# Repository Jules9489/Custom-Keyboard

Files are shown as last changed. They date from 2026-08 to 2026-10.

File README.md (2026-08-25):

# Custom-Keyboard

Plan:

65% Keyboard

Rotary Encoder for Media Controls 

Foam Padding in the Case 

Result:

A nice-looking 65% keyboard that has a rotary encoder for media controls.

It took me a while to make because I ran into different problems along the way, but I managed to fix them eventually. I learned a bit of RMK and a bit more about PCB design, as I had previously made a MacroPad using QMK but had a few flaws, and so I was able to learn from my previous mistakes to make this project better. I built this because I was going to buy a keyboard for my laptop, but then I saw this competition and decided to do it myself.

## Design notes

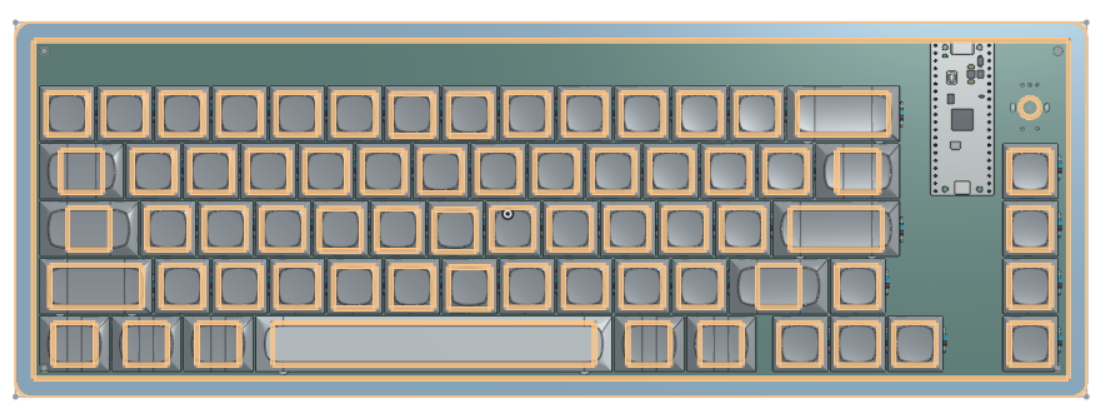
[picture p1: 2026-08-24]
Images/Finished Keyboard plate design.png

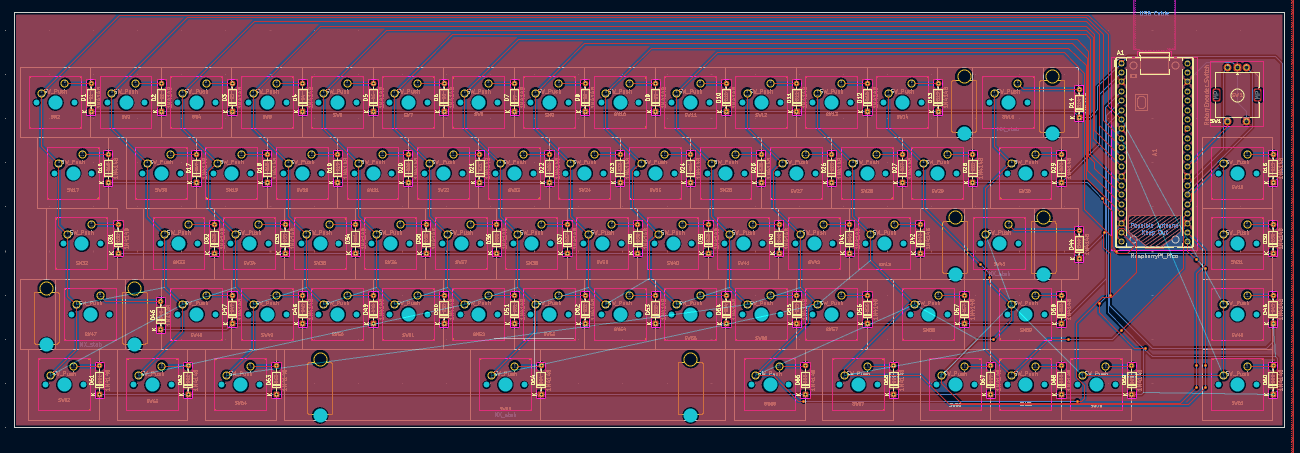
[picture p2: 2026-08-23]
Images/NotCompletedPCB.png

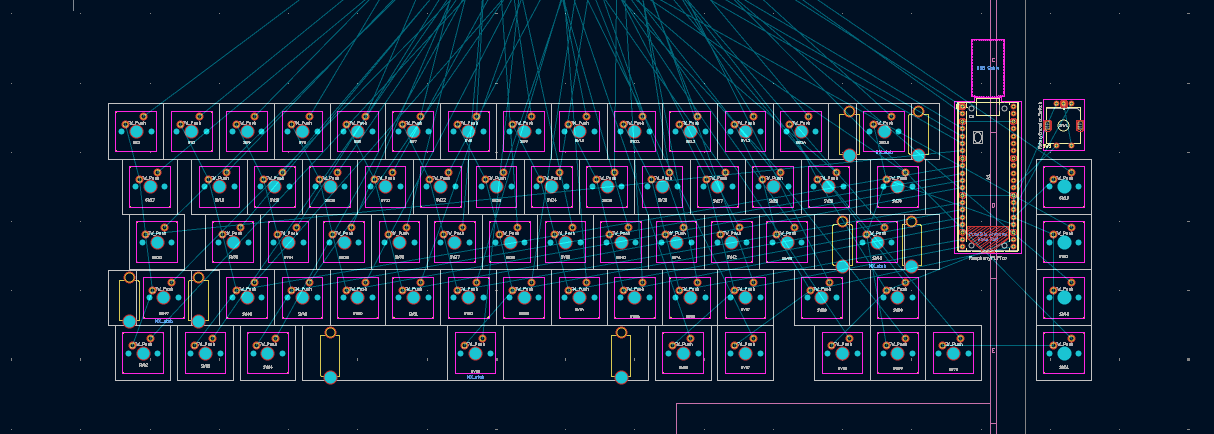
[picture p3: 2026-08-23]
Images/Keyboardlayout.png

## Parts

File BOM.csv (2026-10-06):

Id | Designator | Footprint | Quantity | Designation | Supplier and ref
1 | D39,D10,D55,D16,D58,D1,D57,D61,D18,D30,D64,D28,D23,D45,D41,D66,D2,D62,D56,D4,D29,D38,D24,D22,D43,D17,D21,D12,D52,D53,D25,D9,D5,D31,D42,D11,D37,D6,D60,D49,D36,D63,D51,D67,D20,D8,D32,D65,D15,D19,D48,D47,D7,D3,D54,D14,D46,D26,D13,D44,D33,D40,D59,D35,D27,D50,D34 | D_DO-35_SOD27_P7.62mm_Horizontal | 67 | 1N4148 | https://www.aliexpress.com/item/1005009379098965.html?mp=1 | $3.91
2 | SW52,SW11,SW24,SW63,SW28,SW12,SW38,SW57,SW55,SW8,SW16,SW17,SW26,SW61,SW58,SW40,SW51,SW50,SW4,SW15,SW56,SW2,SW47,SW41,SW44,SW39,SW67,SW10,SW21,SW9,SW45,SW59,SW49,SW19,SW43,SW14,SW3,SW53,SW20,SW13,SW54,SW30,SW36,SW27,SW34,SW48,SW31,SW33,SW65,SW7,SW66,SW64,SW46,SW42,SW5,SW32,SW25,SW23,SW18,SW22,SW68,SW62,SW6,SW35,SW60,SW37,SW29 | SW_MX_1u | 67 | SW_Push | https://www.aliexpress.com/item/1005010169995953.html?mp=1 | $19.03
3 | S1,S2,S3,S4 | STAB_MX_P_2u | 2 | MX_stab | https://www.aliexpress.com/item/1005004286282216.html?mp=1 | $23.75
4 | SW1 | ROT_Alps_EC11E-Switch | 1 | RotaryEncoder_Switch |  | free
5 | A1 | RaspberryPi_Pico_Common_THT | 1 | RaspberryPi_Pico | https://www.aliexpress.com/item/1005008948799927.html?curPageLogUid=gA2XHZhrixAo | $3.59
6 |  | Eva Foam |  | 1 | https://www.aliexpress.com/item/1005002856054113.html?mp=1
7 |  | Flux |  | 1 | https://www.aliexpress.com/item/1005010513692131.html?mp=1 | $1.35
8 |  | Desoldering wick |  | 1 | https://www.aliexpress.com/item/1005008563077640.html?mp=1 | $1.35
9 |  | O rings |  | 1 | https://www.aliexpress.com/item/1005008292633323.html?mp=1 | $1.35
10 |  | Keycap set |  | 1 | https://www.aliexpress.com/item/1005009502593166.html?mp=1 | $31.68
11 |  | PCB |  | 1 |  | $24.40

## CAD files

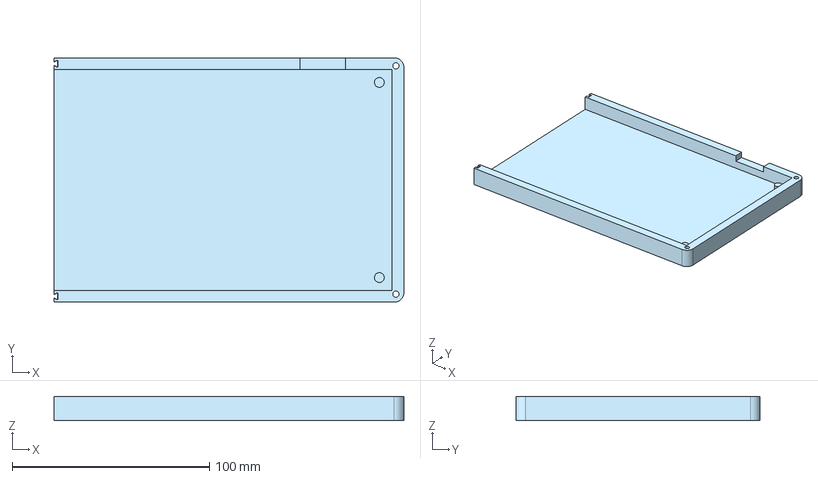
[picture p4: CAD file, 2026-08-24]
CAD/Part Studio 4 - Part 2.step
177.4 x 123.9 x 12.3 mm

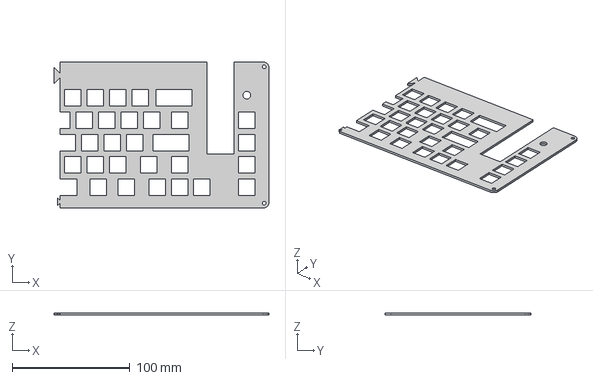
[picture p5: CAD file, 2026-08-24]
CAD/Part Studio 4 - Part 4.step
182.4 x 123.9 x 2.00 mm

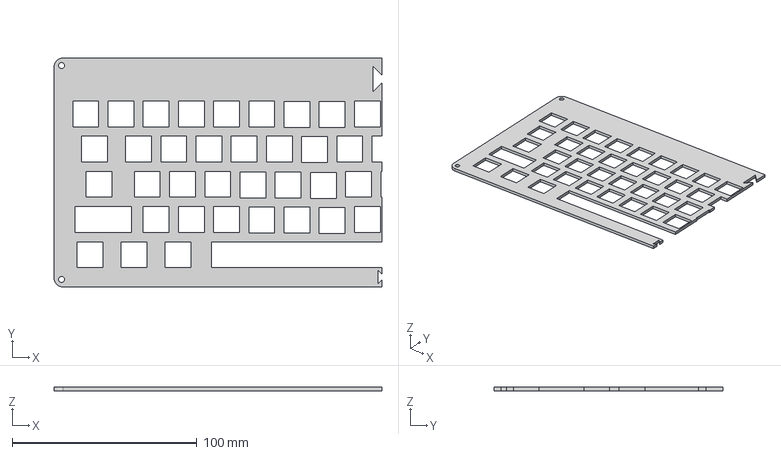
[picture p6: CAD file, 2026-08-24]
CAD/Part Studio 4 - Part 3.step
177.5 x 123.9 x 2.00 mm

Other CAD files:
CAD/Part Studio 4 - Part 1.step
CAD/Part Studio 4 - Part 1.3mf
CAD/Part Studio 4 - Part 2.3mf
CAD/Part Studio 4 - Part 3.3mf
CAD/Part Studio 4 - Part 4.3mf

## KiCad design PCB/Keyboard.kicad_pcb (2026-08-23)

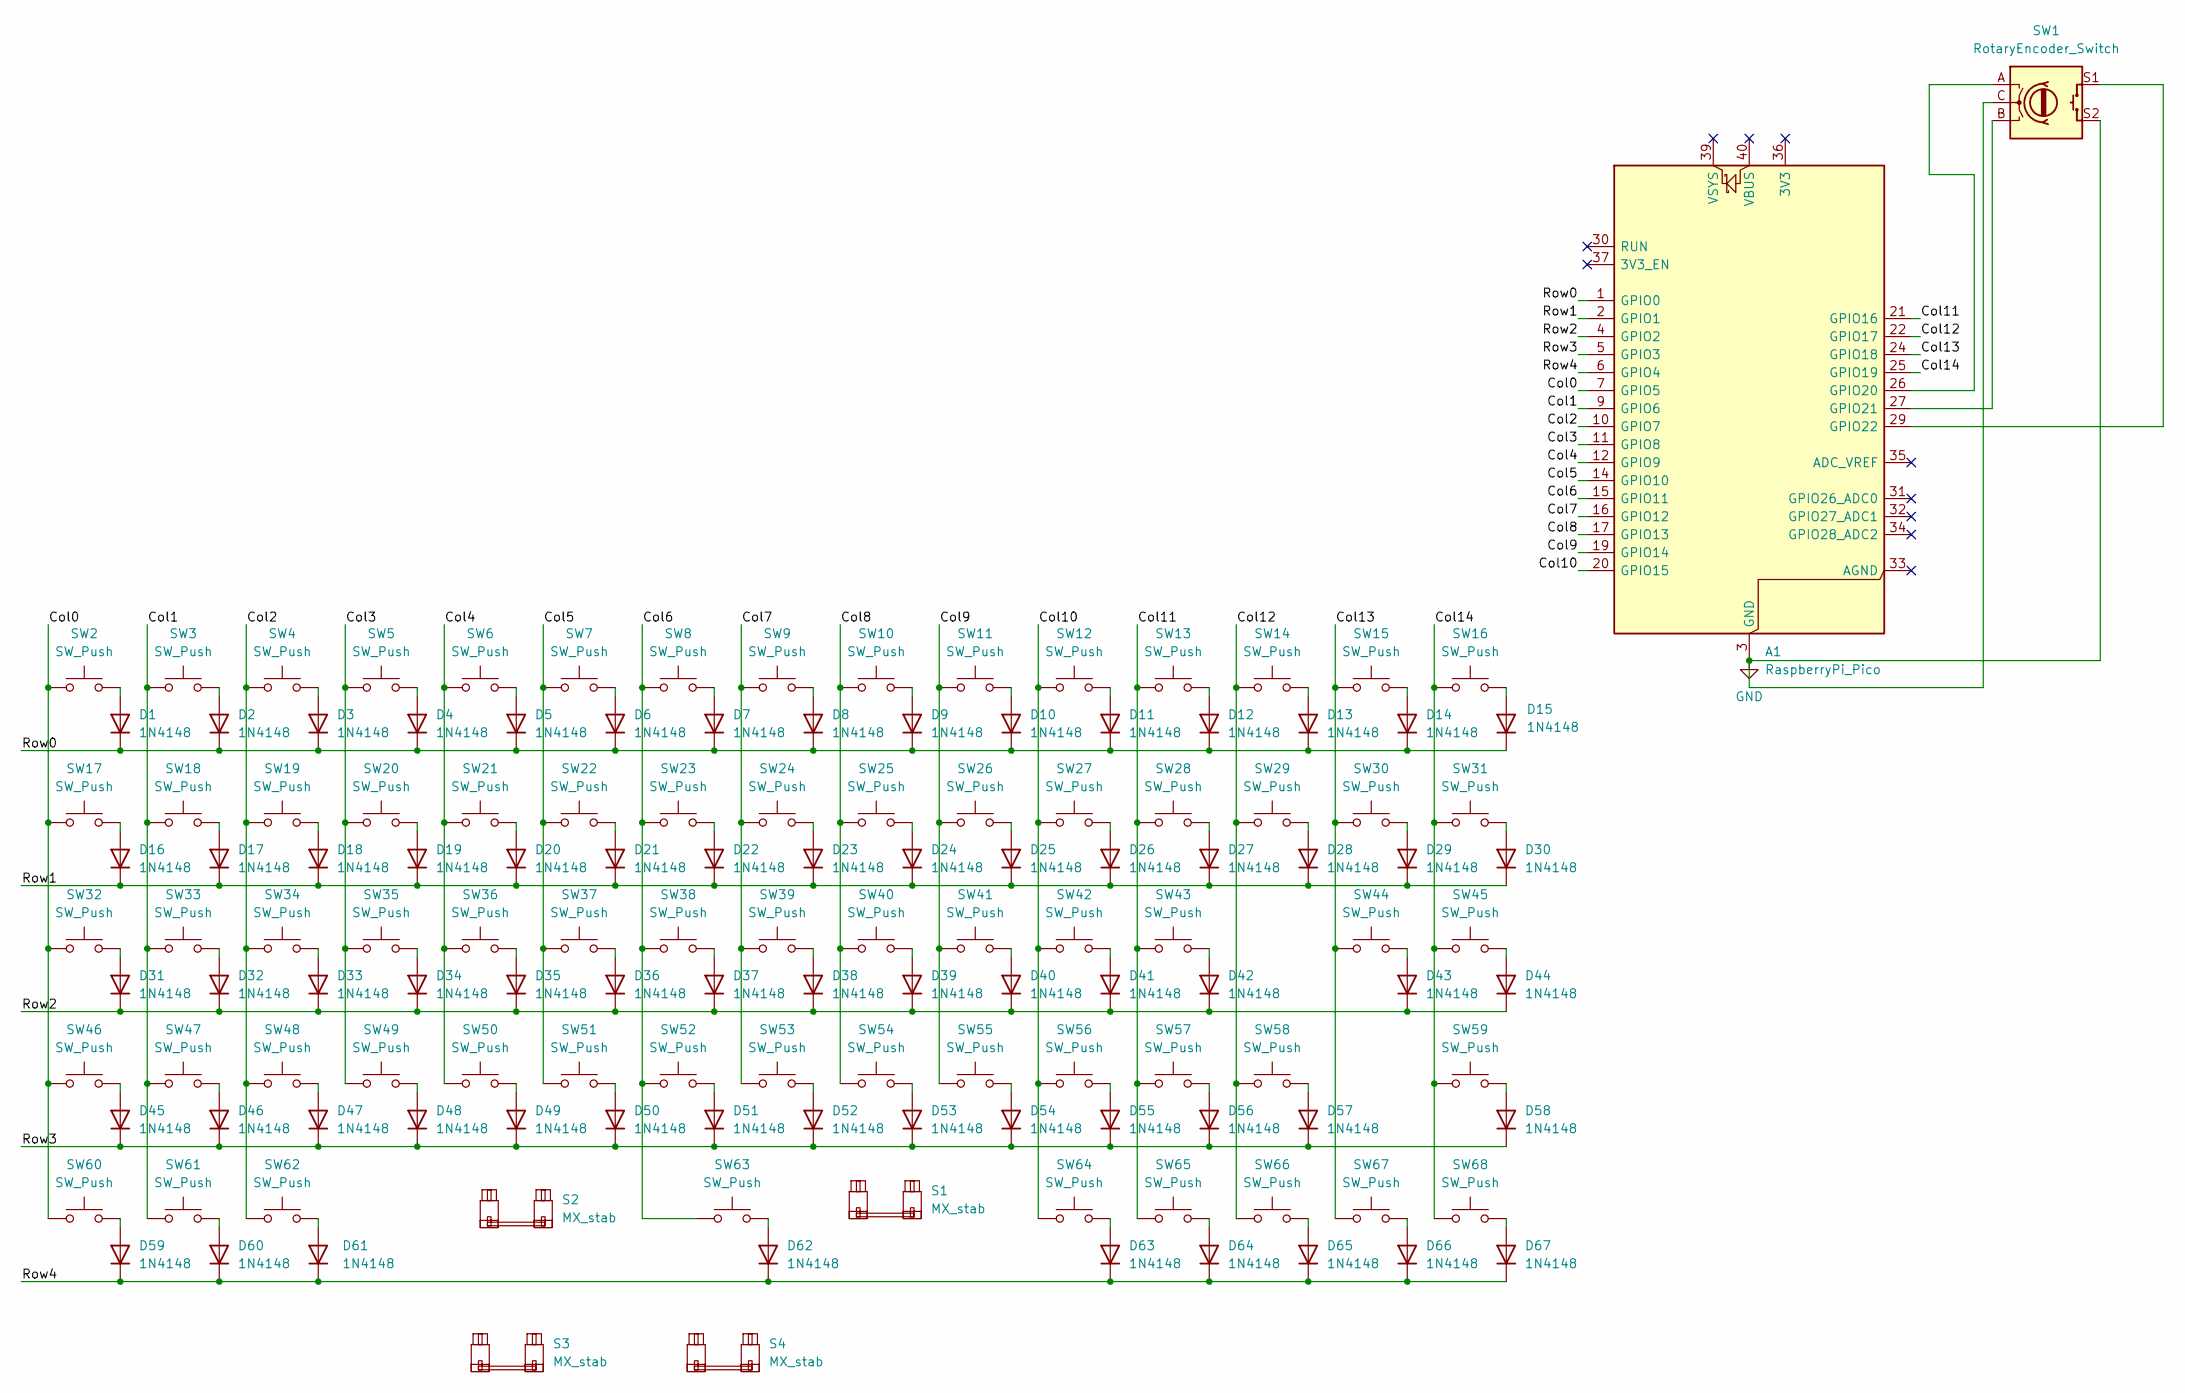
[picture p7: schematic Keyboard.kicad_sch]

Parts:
A1: RaspberryPi_Pico; RaspberryPi_Pico_Common_THT
D1, D2, D3, D4, D5, D6, D7, D8, D9, D10, D11, D12, D13, D14, D15, D16, D17, D18, D19, D20, D21, D22, D23, D24, D25, D26, D27, D28, D29, D30, D31, D32, D33, D34, D35, D36, D37, D38, D39, D40, D41, D42, D43, D44, D45, D46, D47, D48, D49, D50, D51, D52, D53, D54, D55, D56, D57, D58, D59, D60, D61, D62, D63, D64, D65, D66, D67: 1N4148; D_DO-35_SOD27_P7.62mm_Horizontal
S1: MX_stab; STAB_MX_P_6.25u
S2: MX_stab; STAB_MX_P_2.25u
S3, S4: MX_stab; STAB_MX_P_2u
SW1: RotaryEncoder_Switch; ROT_Alps_EC11E-Switch
SW2, SW3, SW4, SW5, SW6, SW7, SW8, SW9, SW10, SW11, SW12, SW13, SW14, SW15, SW16, SW17, SW18, SW19, SW20, SW21, SW22, SW23, SW24, SW25, SW26, SW27, SW28, SW29, SW30, SW31, SW32, SW33, SW34, SW35, SW36, SW37, SW38, SW39, SW40, SW41, SW42, SW43, SW44, SW45, SW46, SW47, SW48, SW49, SW50, SW51, SW52, SW53, SW54, SW55, SW56, SW57, SW58, SW59, SW60, SW61, SW62, SW63, SW64, SW65, SW66, SW67, SW68: SW_Push; SW_MX_1u

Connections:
/Col0: A1.7 (GPIO5), SW2.1, SW17.1, SW32.1, SW46.1, SW60.1
/Col1: A1.9 (GPIO6), SW3.1, SW18.1, SW33.1, SW47.1, SW61.1
/Col2: A1.10 (GPIO7), SW4.1, SW19.1, SW34.1, SW48.1, SW62.1
/Col3: A1.11 (GPIO8), SW5.1, SW20.1, SW35.1, SW49.1
/Col4: A1.12 (GPIO9), SW6.1, SW21.1, SW36.1, SW50.1
/Col5: A1.14 (GPIO10), SW7.1, SW22.1, SW37.1, SW51.1
/Col6: A1.15 (GPIO11), SW8.1, SW23.1, SW38.1, SW52.1, SW63.1
/Col7: A1.16 (GPIO12), SW9.1, SW24.1, SW39.1, SW53.1
/Col8: A1.17 (GPIO13), SW10.1, SW25.1, SW40.1, SW54.1
/Col9: A1.19 (GPIO14), SW11.1, SW26.1, SW41.1, SW55.1
/Col10: A1.20 (GPIO15), SW12.1, SW27.1, SW42.1, SW56.1, SW64.1
/Col11: A1.21 (GPIO16), SW13.1, SW28.1, SW43.1, SW57.1, SW65.1
/Col12: A1.22 (GPIO17), SW14.1, SW29.1, SW58.1, SW66.1
/Col13: A1.24 (GPIO18), SW15.1, SW30.1, SW44.1, SW67.1
/Col14: A1.25 (GPIO19), SW16.1, SW31.1, SW45.1, SW59.1, SW68.1
/Row0: A1.1 (GPIO0), D1.1 (K), D2.1 (K), D3.1 (K), D4.1 (K), D5.1 (K), D6.1 (K), D7.1 (K), D8.1 (K), D9.1 (K), D10.1 (K), D11.1 (K), D12.1 (K), D13.1 (K), D14.1 (K), D15.1 (K)
/Row1: A1.2 (GPIO1), D16.1 (K), D17.1 (K), D18.1 (K), D19.1 (K), D20.1 (K), D21.1 (K), D22.1 (K), D23.1 (K), D24.1 (K), D25.1 (K), D26.1 (K), D27.1 (K), D28.1 (K), D29.1 (K), D30.1 (K)
/Row2: A1.4 (GPIO2), D31.1 (K), D32.1 (K), D33.1 (K), D34.1 (K), D35.1 (K), D36.1 (K), D37.1 (K), D38.1 (K), D39.1 (K), D40.1 (K), D41.1 (K), D42.1 (K), D43.1 (K), D44.1 (K)
/Row3: A1.5 (GPIO3), D45.1 (K), D46.1 (K), D47.1 (K), D48.1 (K), D49.1 (K), D50.1 (K), D51.1 (K), D52.1 (K), D53.1 (K), D54.1 (K), D55.1 (K), D56.1 (K), D57.1 (K), D58.1 (K)
/Row4: A1.6 (GPIO4), D59.1 (K), D60.1 (K), D61.1 (K), D62.1 (K), D63.1 (K), D64.1 (K), D65.1 (K), D66.1 (K), D67.1 (K)
GND: A1.3 (GND), A1.8 (GND), A1.13 (GND), A1.18 (GND), A1.23 (GND), A1.28 (GND), A1.38 (GND), SW1.C, SW1.S2
unnamed: A1.26 (GPIO20), SW1.A
unnamed: A1.27 (GPIO21), SW1.B
unnamed: A1.29 (GPIO22), SW1.S1
unnamed: D1.2 (A), SW2.2
unnamed: D2.2 (A), SW3.2
unnamed: D3.2 (A), SW4.2
unnamed: D4.2 (A), SW5.2
unnamed: D5.2 (A), SW6.2
unnamed: D6.2 (A), SW7.2
unnamed: D7.2 (A), SW8.2
unnamed: D8.2 (A), SW9.2
unnamed: D9.2 (A), SW10.2
unnamed: D10.2 (A), SW11.2
unnamed: D11.2 (A), SW12.2
unnamed: D12.2 (A), SW13.2
unnamed: D13.2 (A), SW14.2
unnamed: D14.2 (A), SW15.2
unnamed: D15.2 (A), SW16.2
unnamed: D16.2 (A), SW17.2
unnamed: D17.2 (A), SW18.2
unnamed: D18.2 (A), SW19.2
unnamed: D19.2 (A), SW20.2
unnamed: D20.2 (A), SW21.2
unnamed: D21.2 (A), SW22.2
unnamed: D22.2 (A), SW23.2
unnamed: D23.2 (A), SW24.2
unnamed: D24.2 (A), SW25.2
unnamed: D25.2 (A), SW26.2
unnamed: D26.2 (A), SW27.2
unnamed: D27.2 (A), SW28.2
unnamed: D28.2 (A), SW29.2
unnamed: D29.2 (A), SW30.2
unnamed: D30.2 (A), SW31.2
unnamed: D31.2 (A), SW32.2
unnamed: D32.2 (A), SW33.2
unnamed: D33.2 (A), SW34.2
unnamed: D34.2 (A), SW35.2
unnamed: D35.2 (A), SW36.2
unnamed: D36.2 (A), SW37.2
unnamed: D37.2 (A), SW38.2
unnamed: D38.2 (A), SW39.2
unnamed: D39.2 (A), SW40.2
unnamed: D40.2 (A), SW41.2
unnamed: D41.2 (A), SW42.2
unnamed: D42.2 (A), SW43.2
unnamed: D43.2 (A), SW44.2
unnamed: D44.2 (A), SW45.2
unnamed: D45.2 (A), SW46.2
unnamed: D46.2 (A), SW47.2
unnamed: D47.2 (A), SW48.2
unnamed: D48.2 (A), SW49.2
unnamed: D49.2 (A), SW50.2
unnamed: D50.2 (A), SW51.2
unnamed: D51.2 (A), SW52.2
unnamed: D52.2 (A), SW53.2
unnamed: D53.2 (A), SW54.2
unnamed: D54.2 (A), SW55.2
unnamed: D55.2 (A), SW56.2
unnamed: D56.2 (A), SW57.2
unnamed: D57.2 (A), SW58.2
unnamed: D58.2 (A), SW59.2
unnamed: D59.2 (A), SW60.2
unnamed: D60.2 (A), SW61.2
unnamed: D61.2 (A), SW62.2
unnamed: D62.2 (A), SW63.2
unnamed: D63.2 (A), SW64.2
unnamed: D64.2 (A), SW65.2
unnamed: D65.2 (A), SW66.2
unnamed: D66.2 (A), SW67.2
unnamed: D67.2 (A), SW68.2

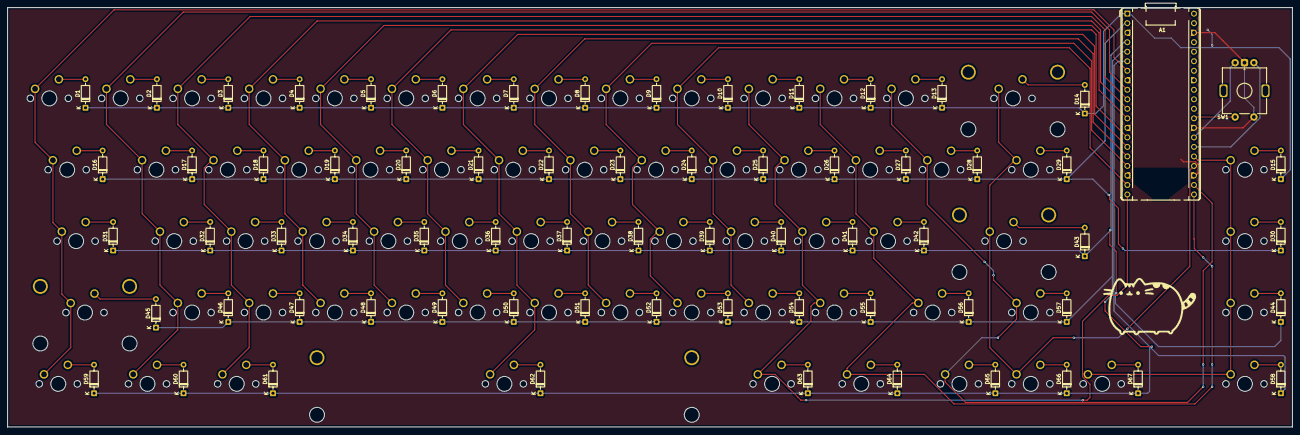
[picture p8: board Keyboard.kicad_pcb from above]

Board: 2 copper layers, 342.9 x 111.9 mm, 140 parts (0 on the bottom side), 91 nets.

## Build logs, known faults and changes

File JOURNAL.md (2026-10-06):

# Journal

## Schematic 
After 3 hours, I finished the schematic, which was quite fun but difficult. 

I fixed the duplicate column, which I had for some reason.

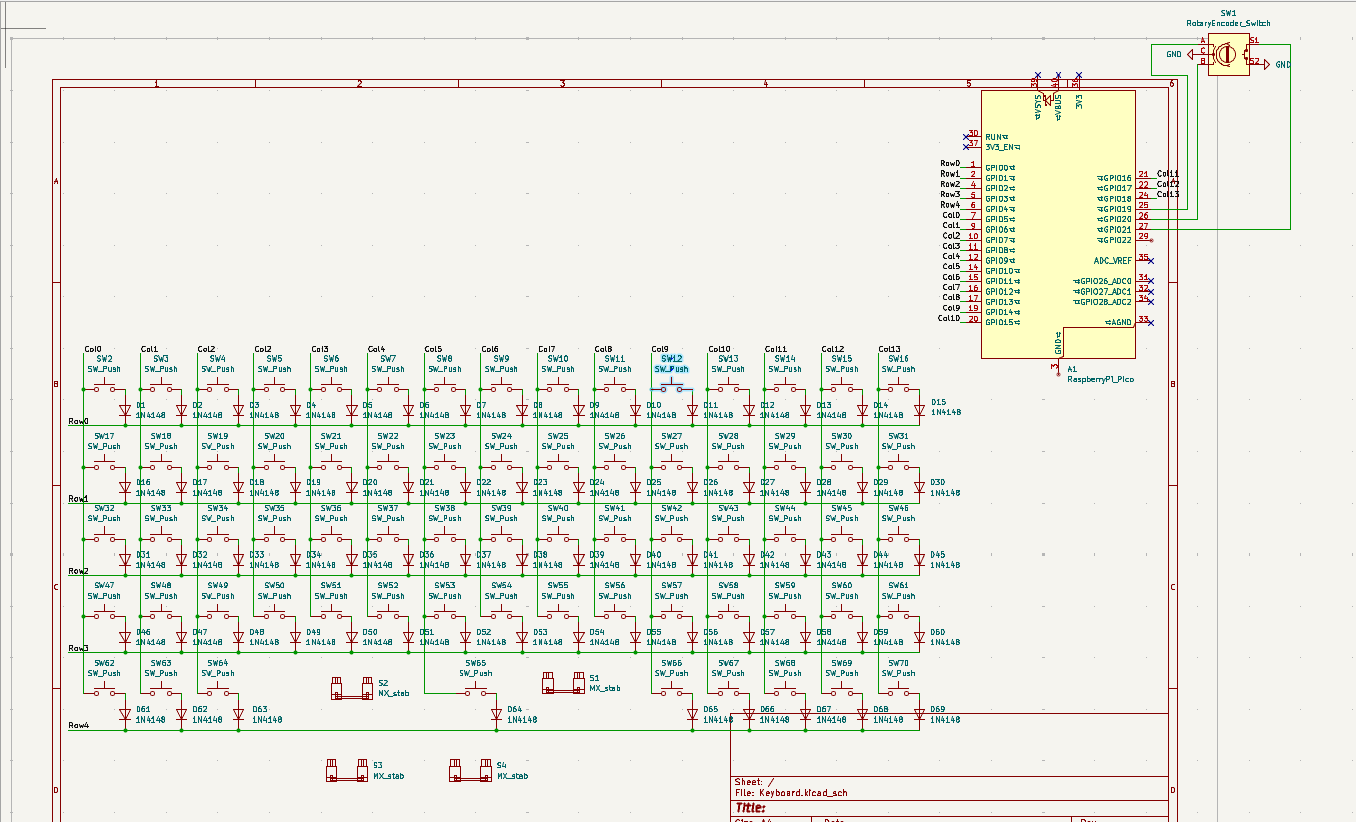
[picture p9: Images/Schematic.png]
Schematic


**Total time: 3 Hours**

## PCB Design 
It then took me 3 hours to have a semi-completed keyboard layout; this took a while as I had to restart multiple times because I messed it up.

I think Fixed the issue of two extra keys, which took longer than I'd like to admit

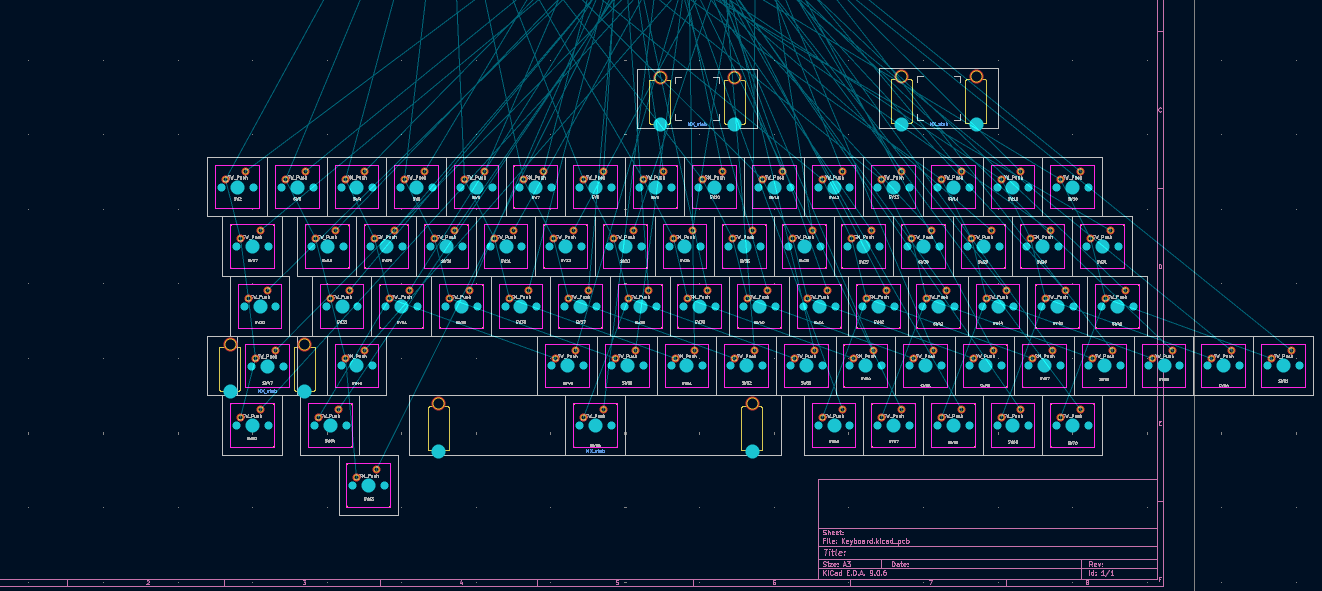
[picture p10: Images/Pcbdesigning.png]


After another 3 hours, I finished the PCB.

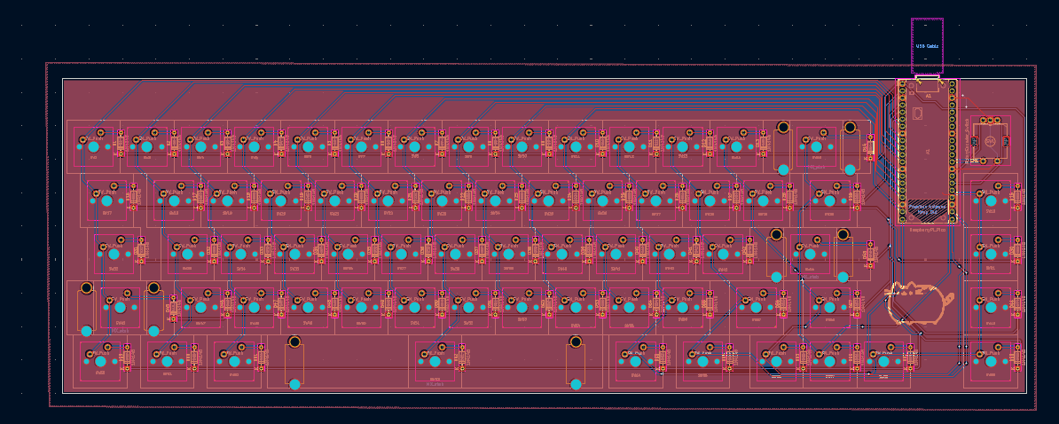
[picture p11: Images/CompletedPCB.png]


And then I spent another hour fixing issues.

Then I spent another hour adding models to my PCB and exporting it into Onshape, which took a while because I couldn't find any models.

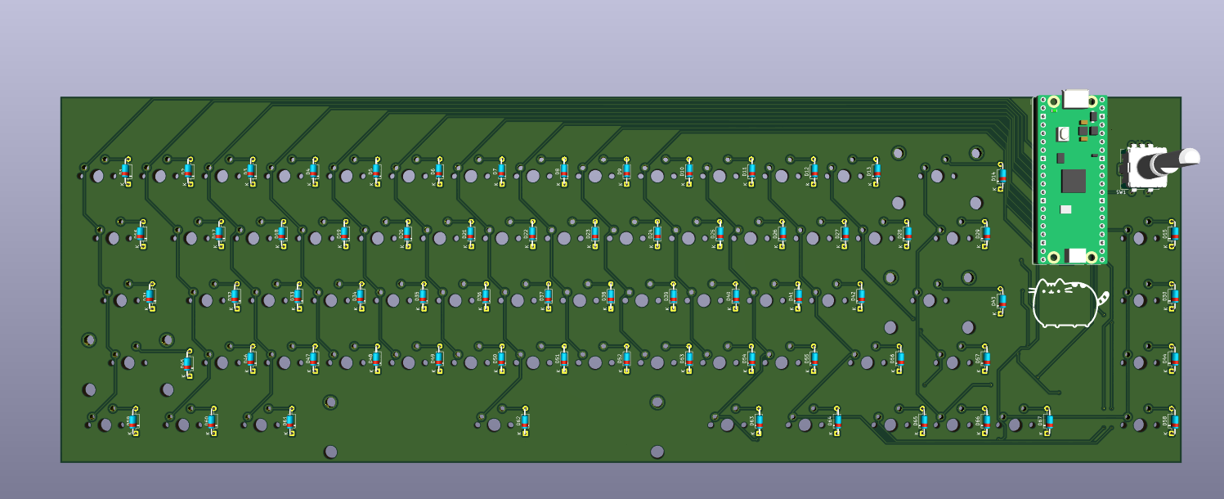
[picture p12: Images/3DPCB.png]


**Total time: 7 Hours**

## Case Design

I spent 2 hours making the case and starting the key plate cutout. 

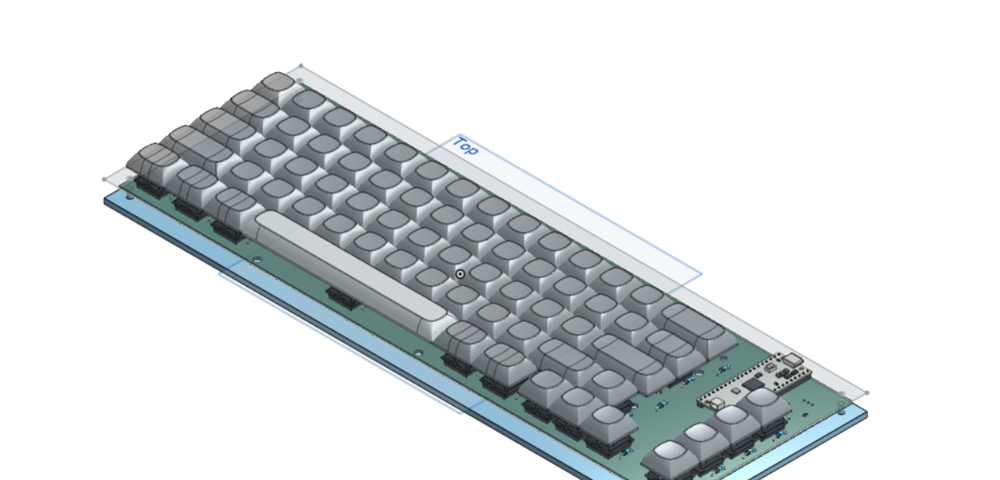
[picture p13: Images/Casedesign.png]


After another hour, I finished the plate cutout. 

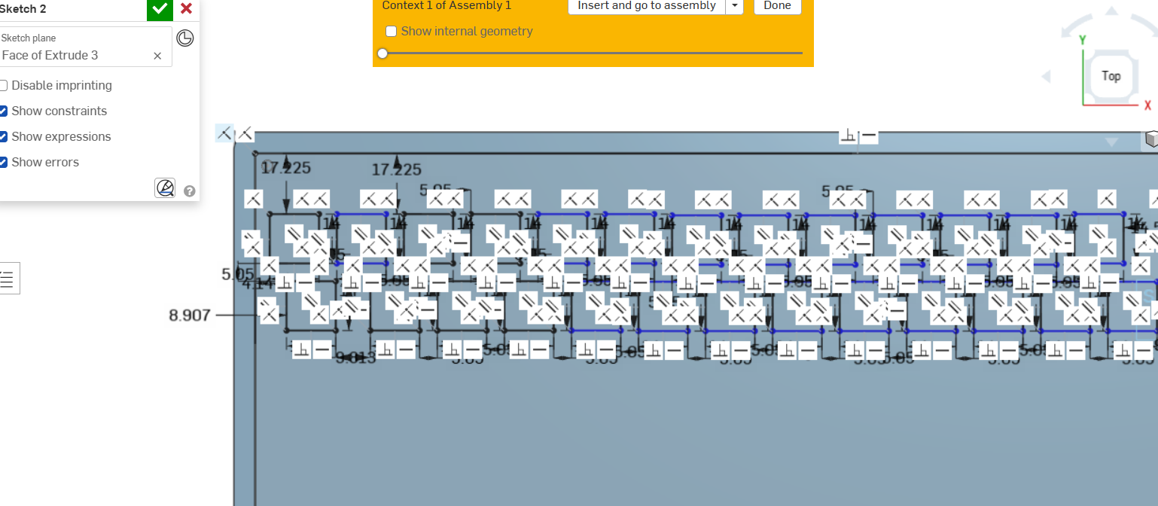
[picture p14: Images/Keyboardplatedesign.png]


3 hours later, I finished the case.

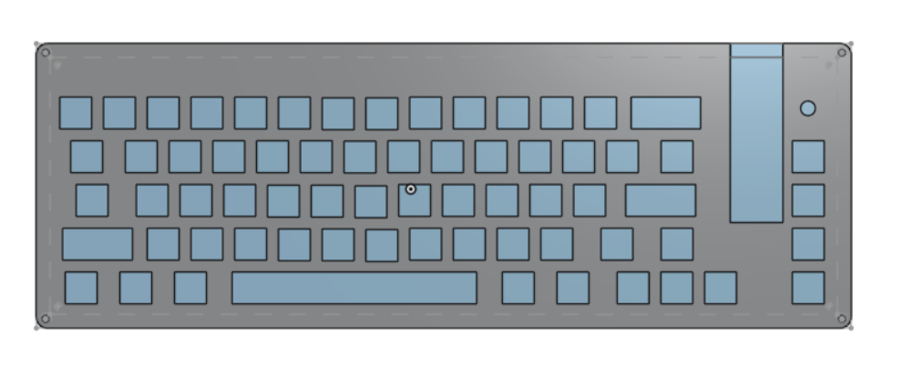
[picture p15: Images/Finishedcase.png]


After that, I spent another 1 hour splitting it into two parts for 3d printing.

**Total time: 7 Hours**

## Firmware
Then I spent 2 hours making the Firmware using RMK, which was the last thing I needed to do for this project.

**Total time: 2 Hours**

*Total Project time: 33 hours*

## Extra 

I created an extra case design that is gasket-mounted(which is why I have included O-rings in my BOM), which I will not count towards the final time.

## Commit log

2026-08-22 Create Pcb
2026-08-22 Add rotary encoder for media controls to plan
2026-08-22 Rename Screenshot 2026-08-22 194412.png to Schematic.png
2026-08-22 Add entry about finishing the schematic
2026-08-23 Rename Screenshot 2026-08-23 111329.png to Pcb designing.png
2026-08-23 Add entry about schematic and keyboard layout progress
2026-08-23 Rename Screenshot 2026-08-23 151509.png to Completed PCB.png
2026-08-23 Rename Completed PCB.png to Not Completed PCB.png
2026-08-23 Rename Screenshot 2026-08-23 163304.png to Completed PCB.png
2026-08-23 Rename Screenshot 2026-08-23 192734.png to Case design.png
2026-08-23 Update Journal with PCB modeling details
    Added details about adding models to the PCB and exporting.
2026-08-23 Rename Screenshot 2026-08-23 205002.png to Keyboard plate design.png
2026-08-24 Rename Screenshot 2026-08-24 121508.png to Finished Keyboard plate design.png
2026-08-24 Add entry about finishing the plate cutout
2026-08-24 Rename Screenshot 2026-08-24 145331.png to Finished case.png
2026-08-24 Revise journal entry with schematic and layout updates
    Updated journal entry with additional details about the schematic and keyboard layout fixes.
2026-08-25 Update README to include foam padding details
    Add mention of foam padding in the case.
2026-09-11 Rename Finished case.png to Finishedcase.png
2026-09-11 Rename Not Completed PCB.png to NotCompleted PCB.png
2026-09-11 Rename NotCompleted PCB.png to NotCompletedPCB.png
2026-09-11 Rename Pcb designing.png to Pcbdesigning.png
2026-09-11 Rename Case design.png to Casedesign.png
2026-09-11 Rename Completed PCB.png to CompletedPCB.png
2026-09-11 Rename Keyboard plate design.png to Keyboardplatedesign.png
2026-10-06 Revise BOM.csv with supplier links and new components
    Updated BOM.csv to include supplier links and additional items.
    [BOM.csv]
2026-10-06 Document extra case design in JOURNAL.md
    Added a section for extra case design details.
2026-10-06 Update BOM.csv with new entries and links
    [BOM.csv]
2026-10-22 Rename Keyboard Fabrication (2).zip to gerbers.zip
2026-10-22 Add schematic image reference in journal
    Added a schematic image reference to the journal entry.
2026-10-22 Modify BOM.csv with new component details
    Updated BOM.csv to reflect new components and pricing.
2026-10-22 Update BOM.csv with new component entries
2026-11-02 Revise BOM.csv with updated components and pricing
    Updated BOM.csv to reflect new item details and prices.
